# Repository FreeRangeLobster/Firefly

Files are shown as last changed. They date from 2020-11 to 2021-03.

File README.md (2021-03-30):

I am an aquarist enthusiast; I have a fully automated fish tank at home.
When my daughter Sofia was born two years ago, I couldn’t really dedicate as much spare time to my fish tank, and was spending it with her instead. She is very curious, and she found the fish tank buttons and indicators very attractive. She was always fiddling with them, pressing them, and enjoyed when the buttons would illuminate – to the point where I had to disable the button internal functionalities, as the poor fish would suffer from a stroboscopic effect otherwise. Cool in a party not cool in a tank
This is when I had an idea: what if I built an interactive table for Sofia, so she has her own buttons to play with (and leave the poor fish alone)? And that’s exactly what I did.
Over the past few weeks I spent some lunch times and evenings designing, building and programming a child friendly interactive table. This is what I did:

The first step was to find a controller with many IO, which should also be able to control addressable LEDs. After some research, I concluded that my weapon of choice will be an ESP-32.

The next task was to design the table and order all the components. My colleagues in the machine shop helped me manufacture the base plate. Note that I upcycled a small sand&water play table, so I only needed to design and manufacture the base to fit on top of it.

When the components arrived and the Perspex base was ready, I wired it all up. This only took a couple of days.

Then the programming started. Fortunately, there is a big community of open software/hardware and a lot of the libraries are already available, which helped me a lot.

On 20th December the system was ready for the tester (my daughter). She enjoyed it a lot and so far the table seems to be withstanding the abuse it’s getting.
I am not quite yet finished with the work. I would still like to add some sounds to it, and perhaps add IOT capabilities and connecting the table to Alexa – “Alexa, red lights please!”
So far we are all happy. Sofia has a custom-made interactive table, I learned something new, and the fish are finally enjoying some quiet time in their tank. This is only one small application aiming to encourage my daughter into STEM, it is never too early!

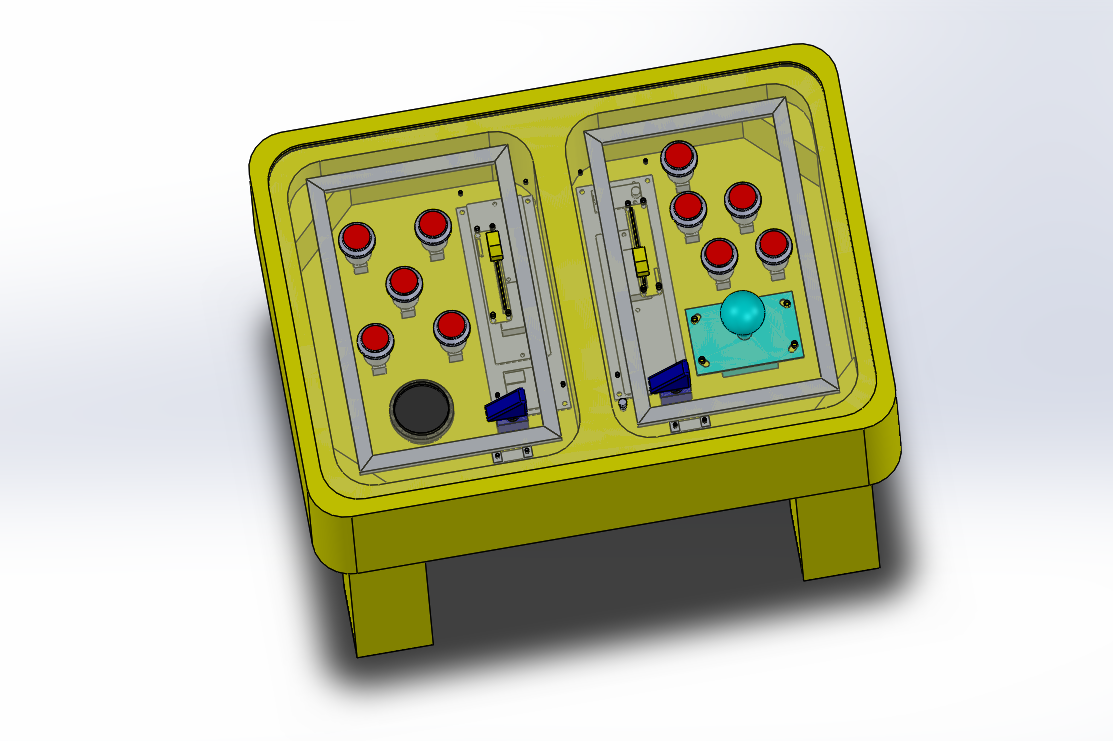
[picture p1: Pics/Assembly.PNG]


Application

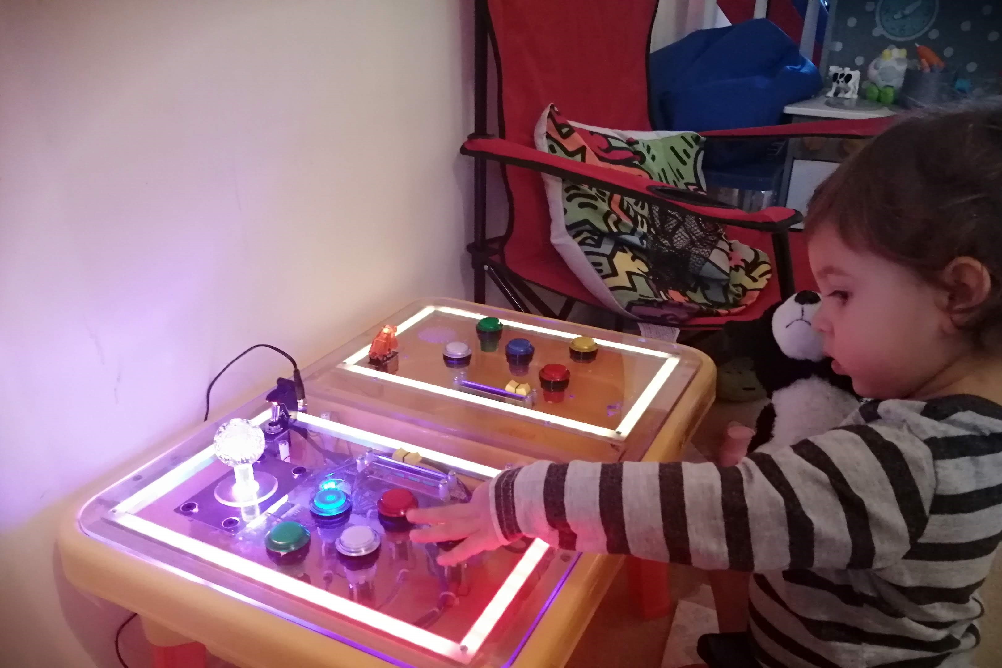
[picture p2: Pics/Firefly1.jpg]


Table with buttons and lights

#TheLight
Inputs
5 buttons
GPIO18
GPIO2
GPIO15
GPIO0

4 Joystick
GPIO36
GPIO39
GPIO34
GPIO35

5 Outputs
GPIO23
GPIO22
GPIO1
GPIO3
GPIO21

CAN
GPIO4 RX
GPIO5 TX

Connect 3V to power the buttons
Test the LEDs of the buttons

40*59*35

Priority Pins
gpio4
gpio5
gpio16
gpio17
gpio18
gpio19
gpio23
gpio25
gpio26
gpio27
gpio32
gpio33

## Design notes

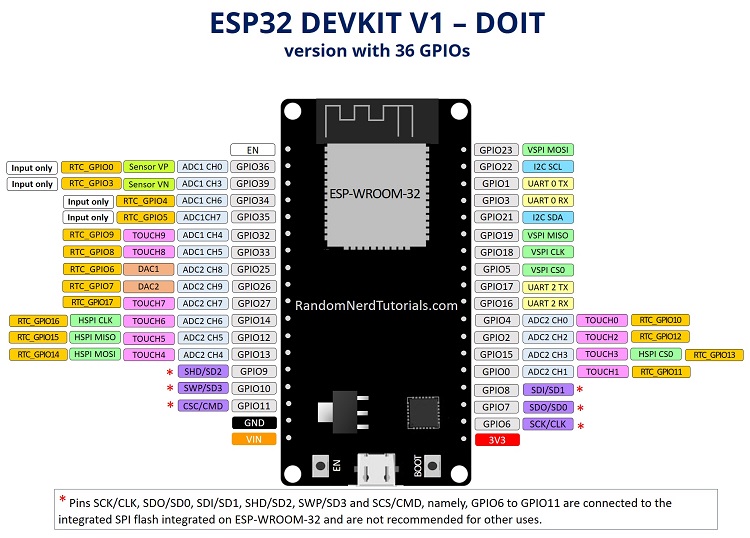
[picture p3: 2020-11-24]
Pics/ESP32-DOIT-DEVKIT-V1-Board-Pinout-36-GPIOs-updated.jpg

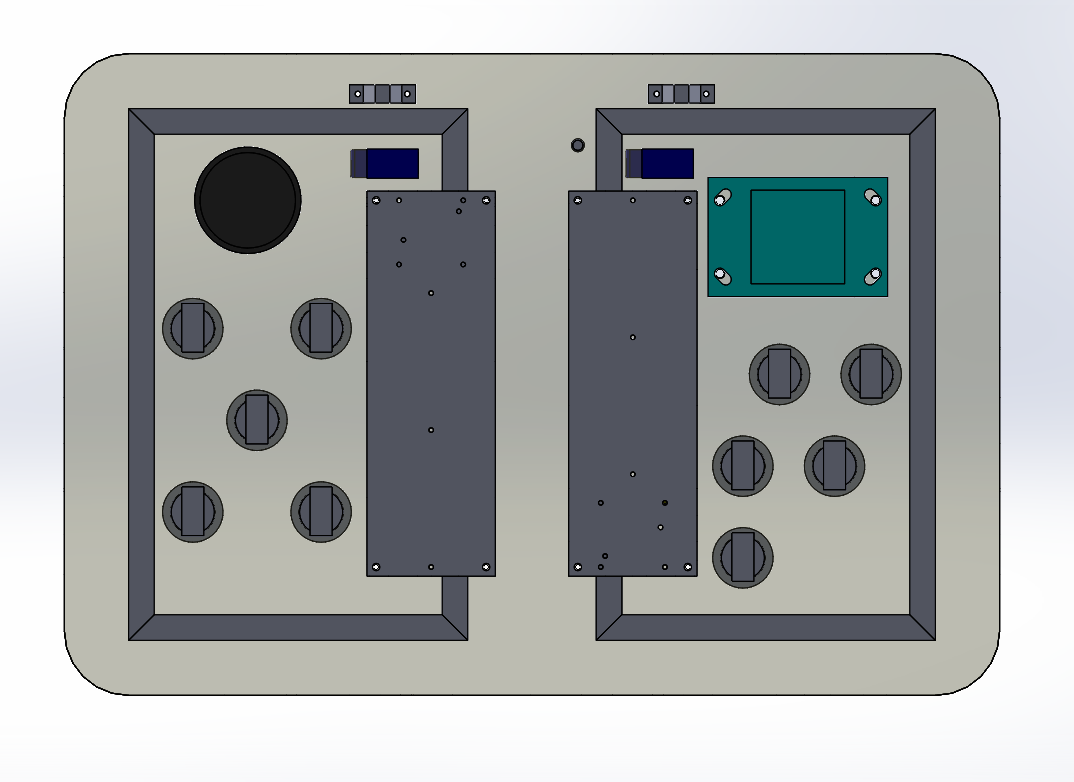
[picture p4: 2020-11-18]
Pics/BottomView.PNG

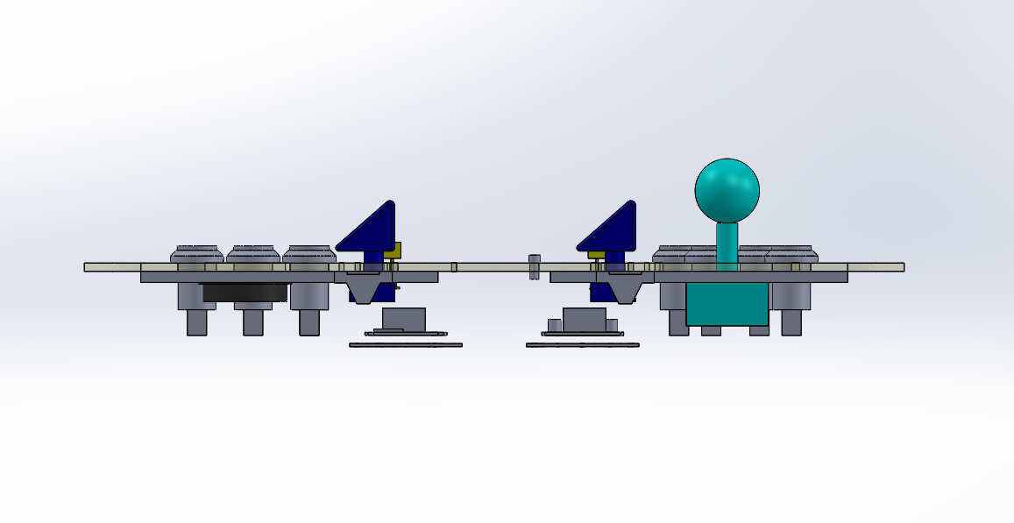
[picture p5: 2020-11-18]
Pics/Table-Less.PNG

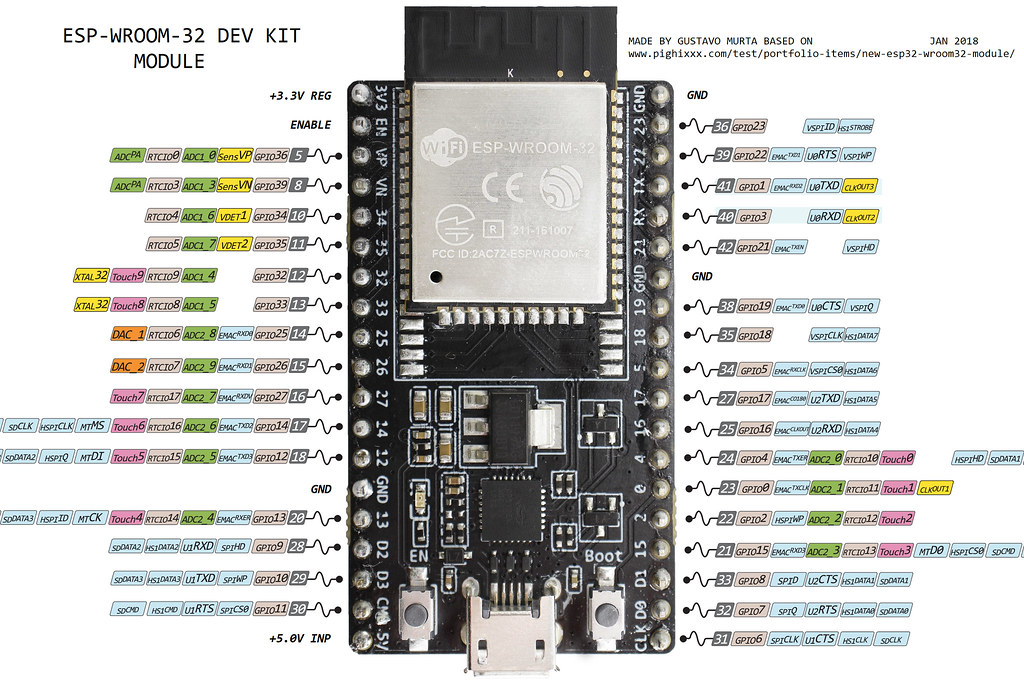
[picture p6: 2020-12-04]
Pics/40089095211_ec1fee0087_b.jpg

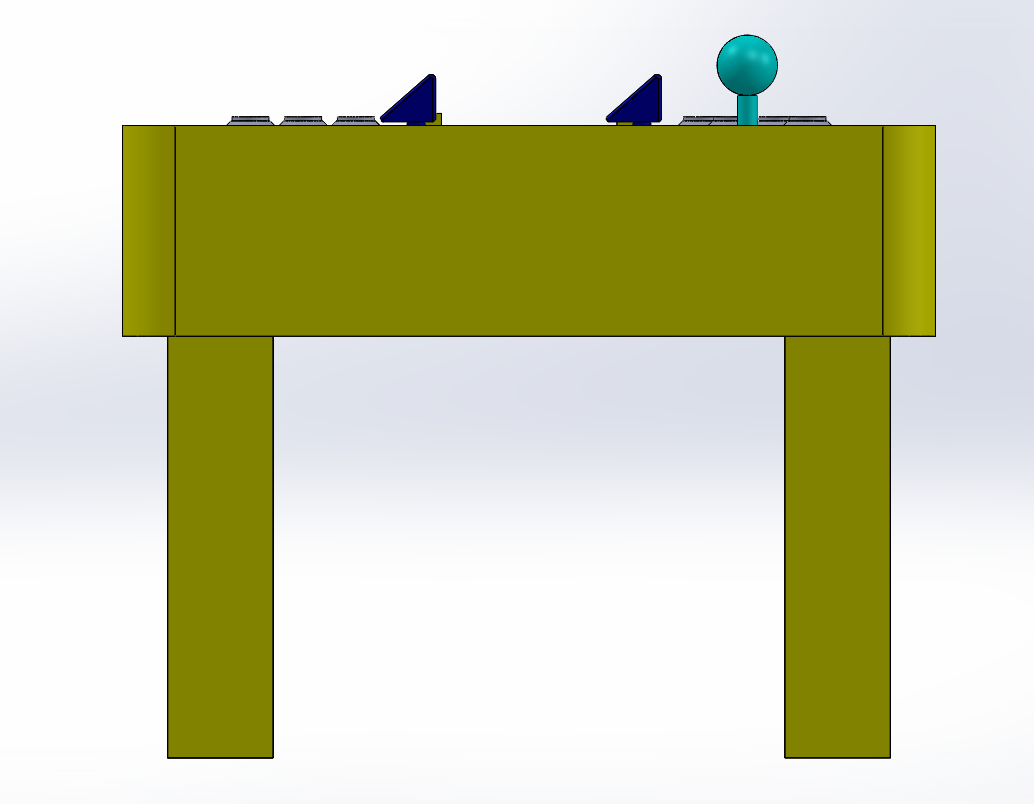
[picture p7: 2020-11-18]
Pics/Side.PNG

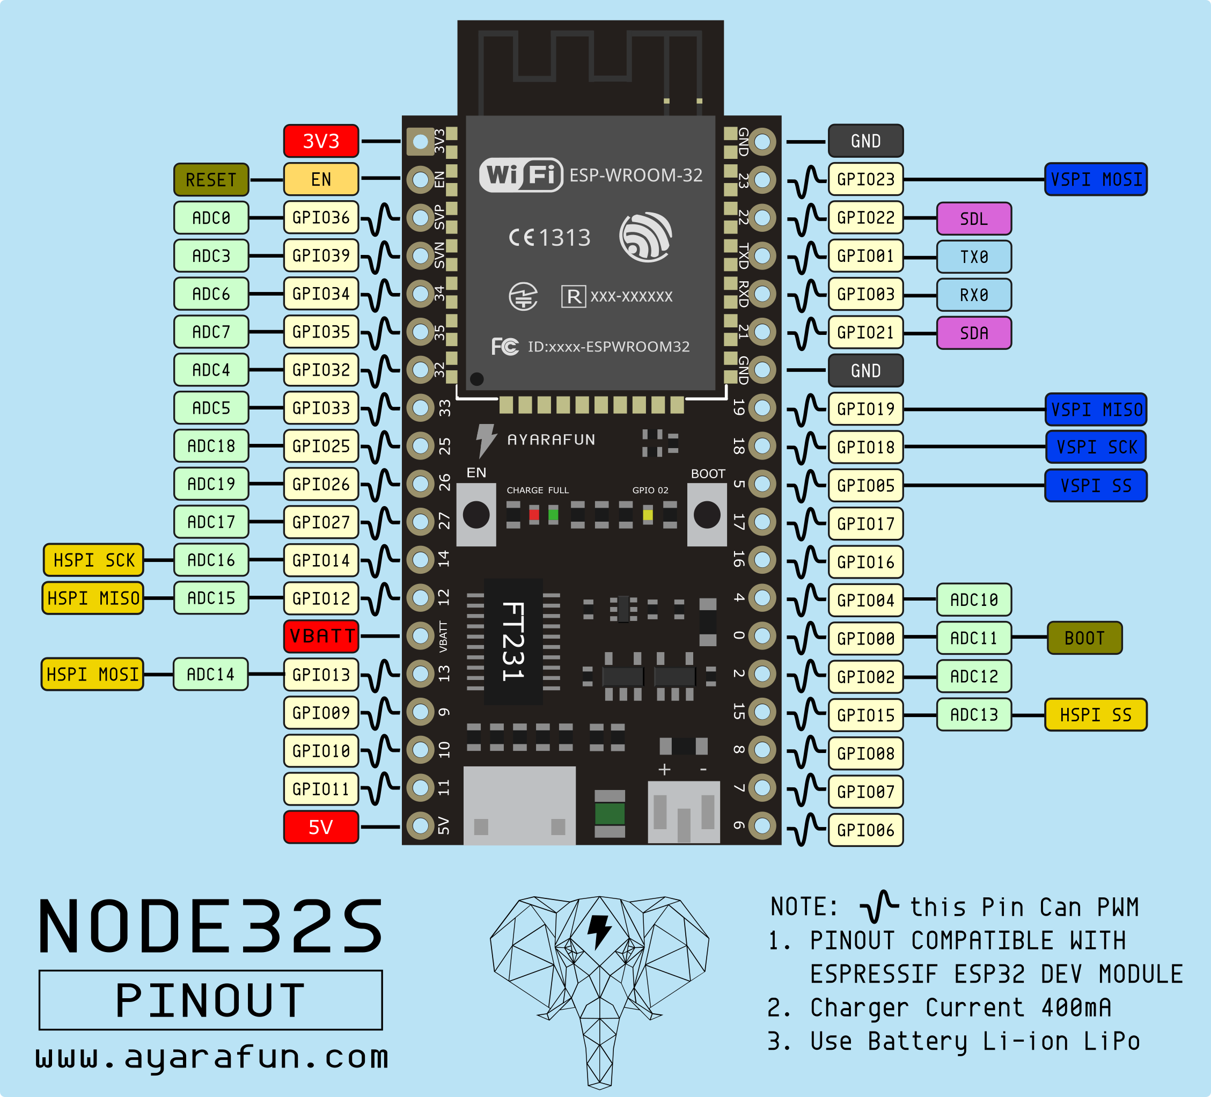
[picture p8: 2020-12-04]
Pics/Pins.png

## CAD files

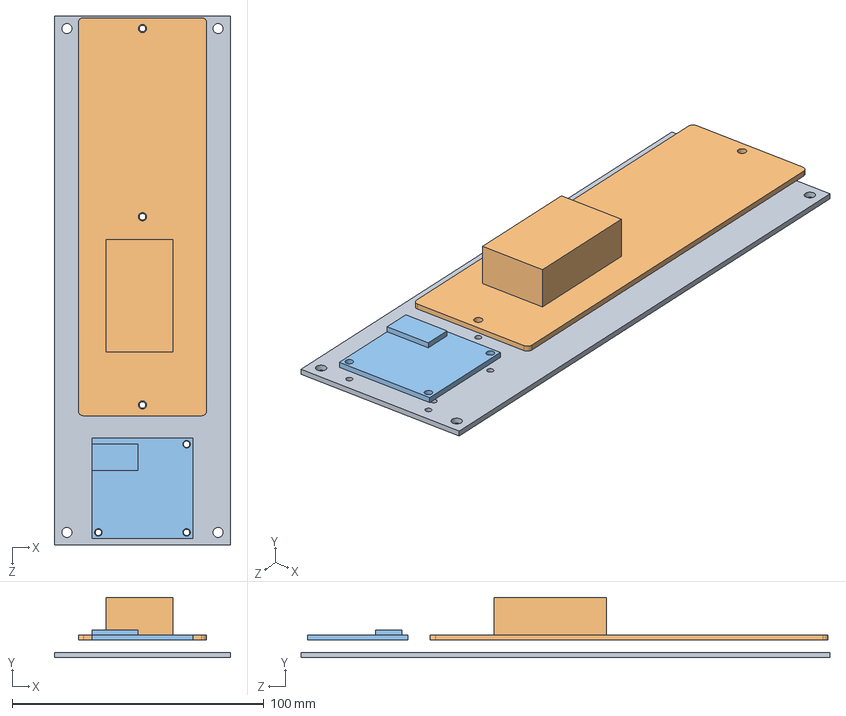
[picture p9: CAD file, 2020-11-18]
TheMechanics/AssPCB1.SLDASM
70.0 x 24.0 x 210.0 mm
PCBHolder
PCB
MP3

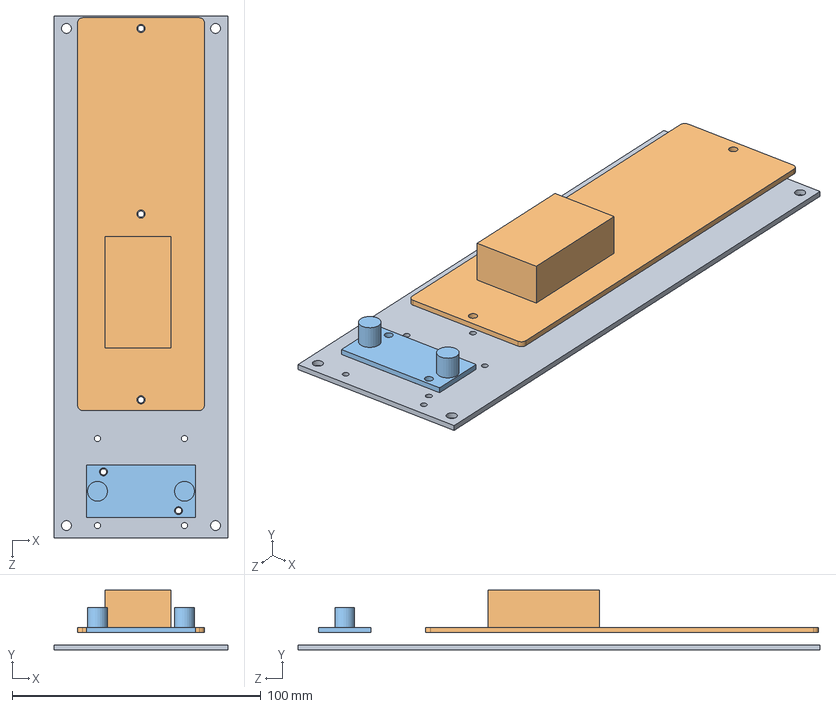
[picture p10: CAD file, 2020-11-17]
TheMechanics/AssPCB2.SLDASM
70.0 x 24.0 x 210.0 mm
PCBHolder
PCB
PSU

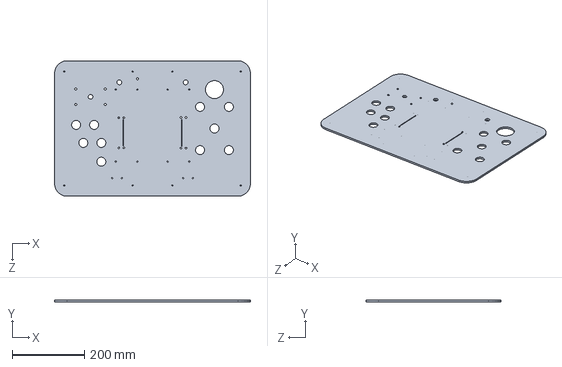
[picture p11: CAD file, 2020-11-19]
TheMechanics/Perspex Panel.SLDPRT
544.0 x 5.00 x 376.0 mm

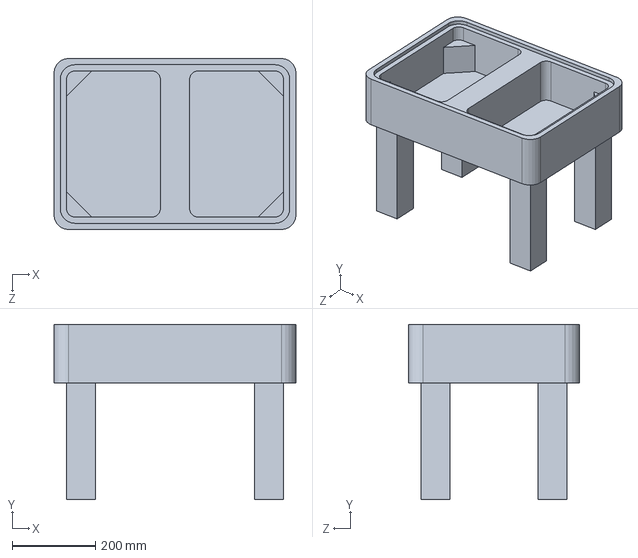
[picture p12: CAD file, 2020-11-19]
TheMechanics/Table.SLDPRT
580.0 x 420.0 x 410.0 mm

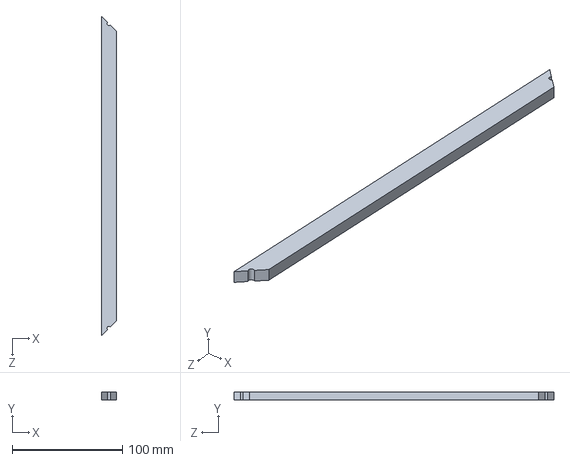
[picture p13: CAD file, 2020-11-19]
TheMechanics/ledChannelSide.SLDPRT
14.0 x 7.00 x 290.0 mm

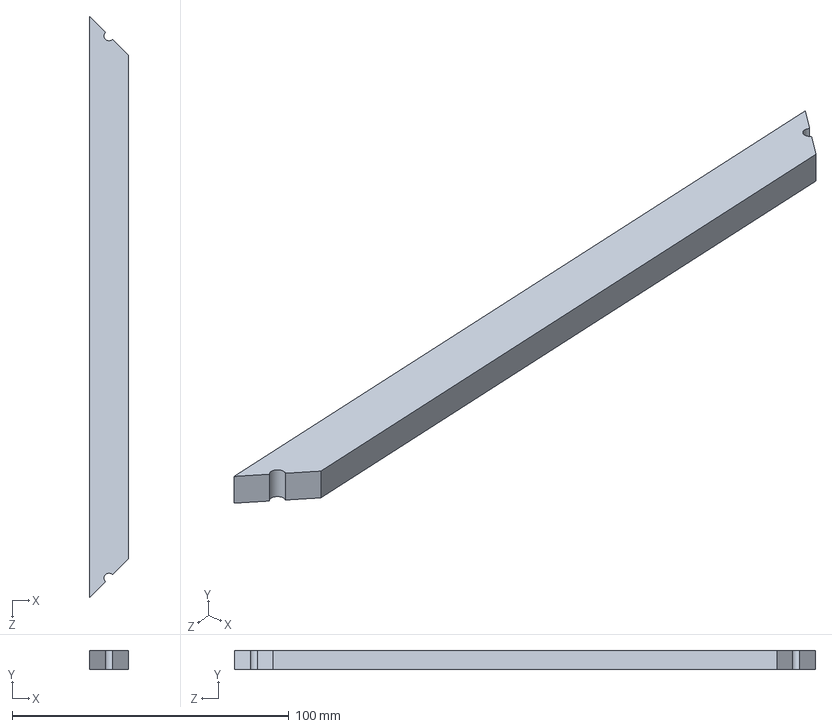
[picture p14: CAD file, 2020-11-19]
TheMechanics/ledChannelTop.SLDPRT
14.0 x 7.00 x 210.0 mm

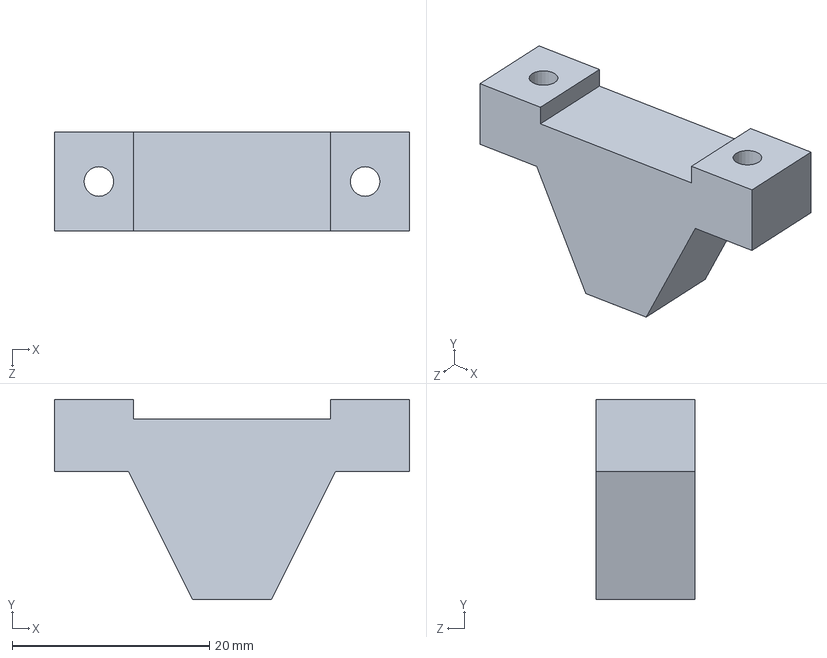
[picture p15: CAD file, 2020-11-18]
TheMechanics/USB Connector.SLDPRT
36.0 x 20.3 x 10.0 mm

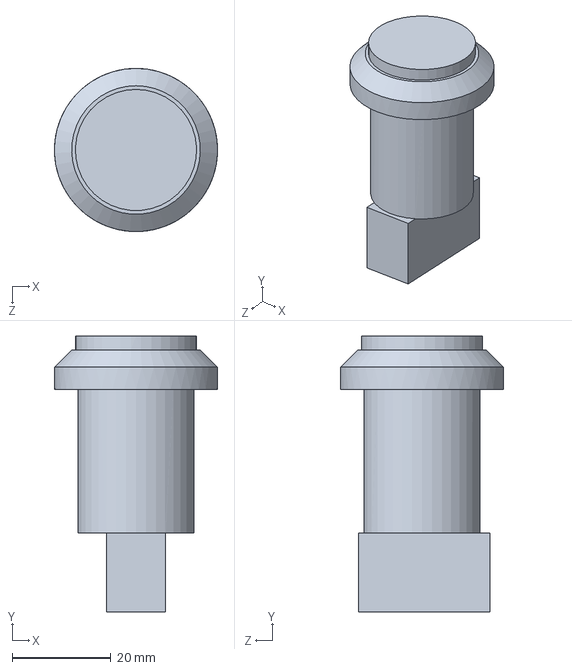
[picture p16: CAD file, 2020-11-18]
TheMechanics/prtPushButton.SLDPRT
33.0 x 55.8 x 33.0 mm

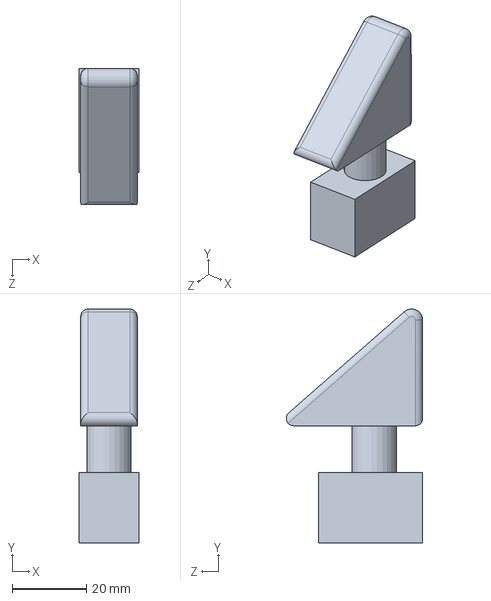
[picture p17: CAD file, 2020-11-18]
TheMechanics/MissileSwitch.SLDPRT
16.0 x 62.9 x 36.7 mm

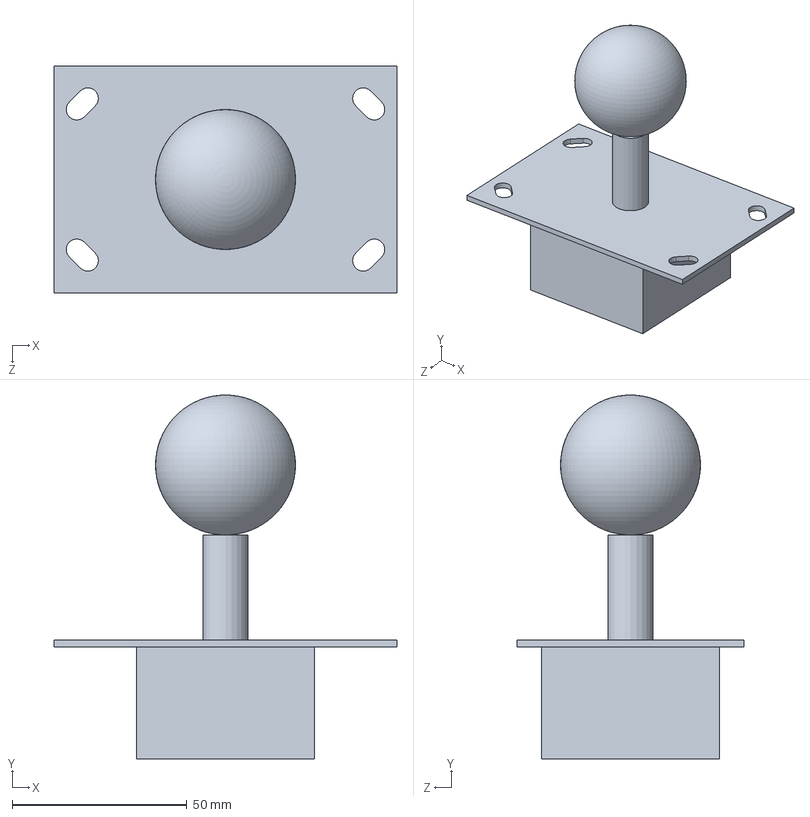
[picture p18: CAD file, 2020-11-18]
TheMechanics/Joystick.SLDPRT
98.0 x 104.0 x 65.0 mm

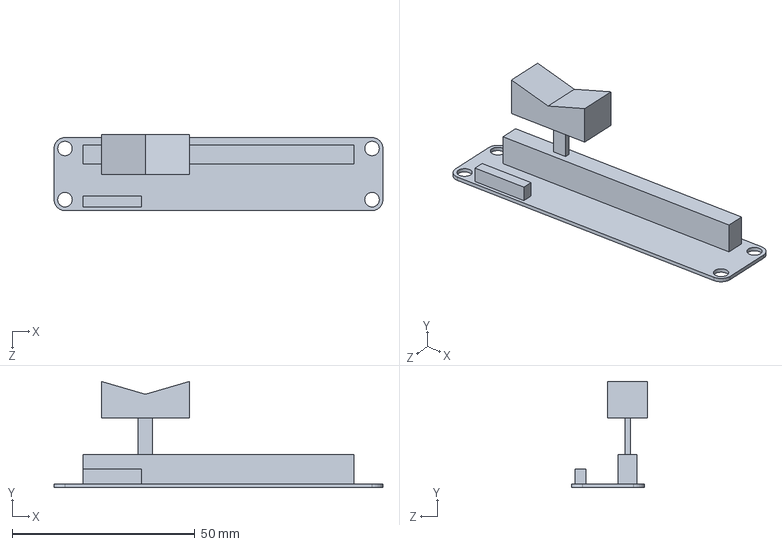
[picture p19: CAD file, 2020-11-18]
TheMechanics/Pot.SLDPRT
90.0 x 29.0 x 20.9 mm

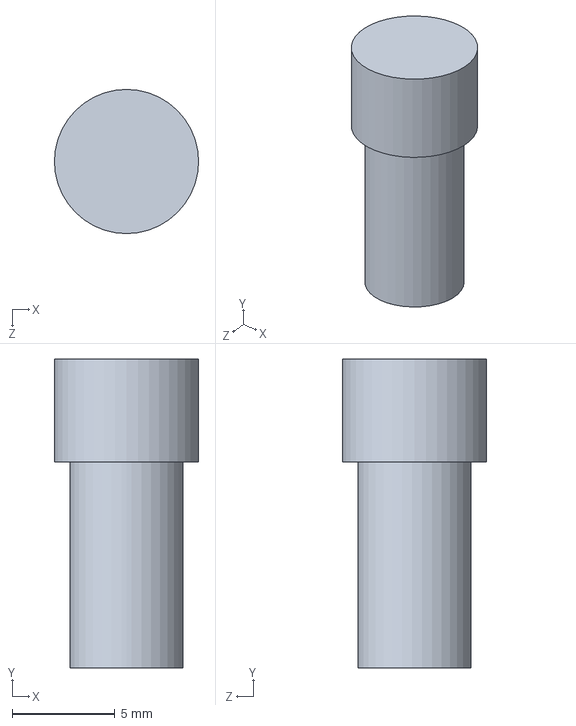
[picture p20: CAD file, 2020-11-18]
TheMechanics/PowerConnector.SLDPRT
7.00 x 15.0 x 7.00 mm

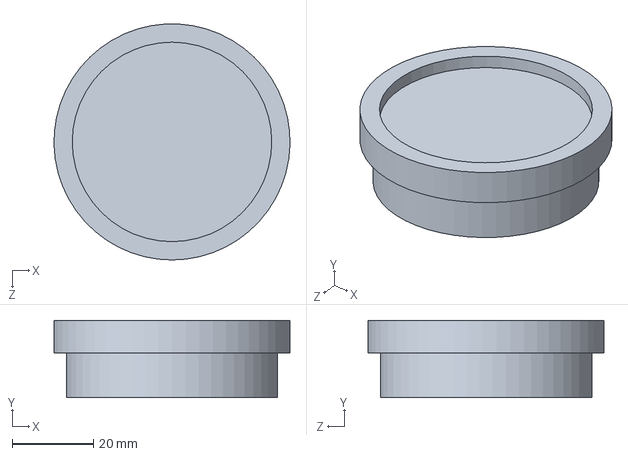
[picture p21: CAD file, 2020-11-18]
TheMechanics/Speaker.SLDPRT
58.0 x 19.0 x 57.9 mm

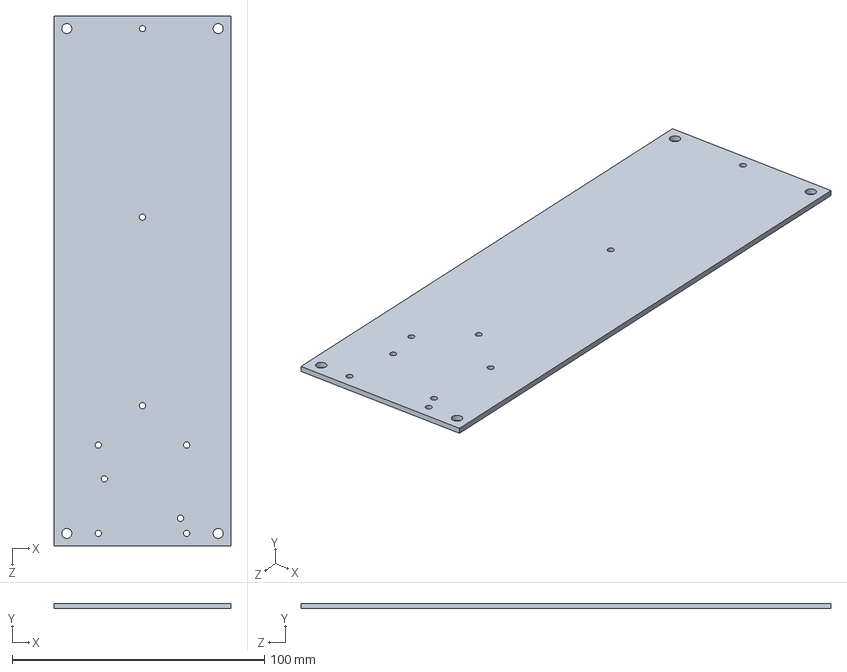
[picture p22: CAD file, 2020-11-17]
TheMechanics/PCBHolder.SLDPRT
70.0 x 2.00 x 210.0 mm

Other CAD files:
TheMechanics/PCB.SLDPRT
TheMechanics/PSU.SLDPRT
TheMechanics/Veroboard.SLDPRT
TheMechanics/MP3.SLDPRT
TheMechanics/PCBHolder.SLDDRW
TheMechanics/Perspex Panel.SLDDRW
TheMechanics/ledChannelSide.SLDDRW
TheMechanics/ledChannelTop.SLDDRW

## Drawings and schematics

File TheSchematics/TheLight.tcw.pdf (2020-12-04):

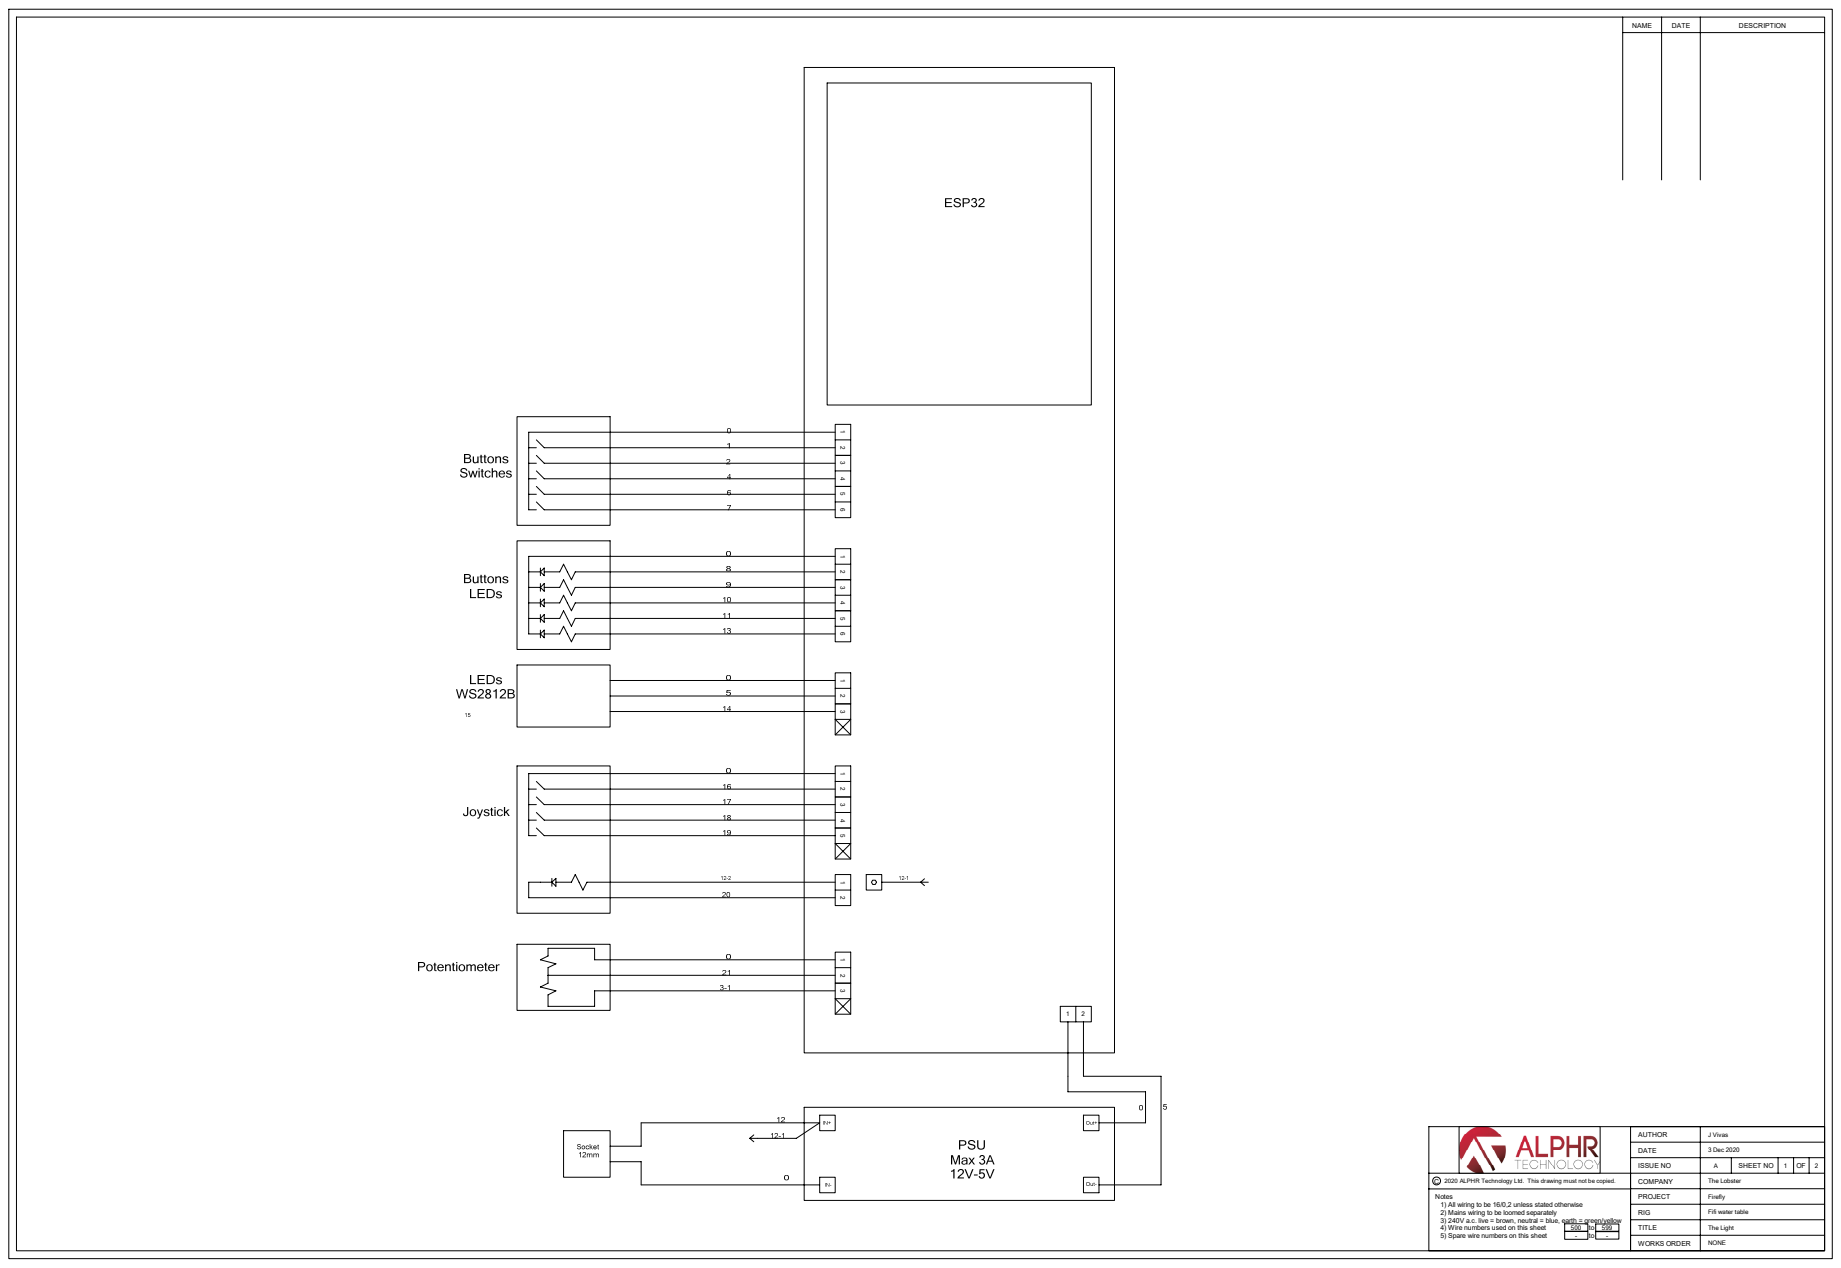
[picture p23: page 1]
NAME; DATE; DESCRIPTION

AUTHOR | J Vivas

DATE | 3 Dec 2020

ISSUE NO | A | SHEET NO | 1 | OF | 2

C 2020 ALPHR Technology Ltd. This drawing must not be copied. | COMPANY | The Lobster

Notes 1) All wiring to be 16/0,2 unless stated otherwise 2) Mains wiring to be loomed separately 3) 240V a.c. live = brown, neutral = blue, earth = green/yellow | PROJECT | Firefly

RIG | Fifi water table

4) Wire numbers used on this sheet
5) Spare wire numbers on this sheet

TITLE | The Light

WORKS ORDER | NONE

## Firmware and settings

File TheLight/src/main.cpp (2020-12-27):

#include <FastLED.h>

// How many leds in your strip?
#define NUM_LEDS 116

// For led chips like WS2812, which have a data line, ground, and power, you just
// need to define DATA_PIN.  For led chipsets that are SPI based (four wires - data, clock,
// ground, and power), like the LPD8806 define both DATA_PIN and CLOCK_PIN
// Clock pin only needed for SPI based chipsets when not using hardware SPI
#define DATA_PIN 3
#define CLOCK_PIN 13
#define LED 2
#define JoystickLamp 27



/*
*        S5                    S1
*|-------------------||-------------------|
*|                   ||                   |
*|                   ||                   |
*|S6               S8|| S4                | S2
*|                   ||                   |
*|       S7          ||        S3         |
*|-------------------||-------------------|
*/

//Right Side
//S8 + S2

//Left Side
//S6 + S4

#define S1s 0
#define S1e 11-1

#define S2s 11
#define S2e 11+18-1

#define S3s 11+18
#define S3e 11+18+11-1

#define S4s 11+18+11
#define S4e 11+18+11+18-1

#define S5s 11+18+11+18
#define S5e 11+18+11+18+11-1

#define S6s 11+18+11+18+11
#define S6e 11+18+11+18+11+18-1

#define S7s 11+18+11+18+11+18
#define S7e 11+18+11+18+11+18+11-1

#define S8s 11+18+11+18+11+18+11
#define S8e 11+18+11+18+11+18+11+18-1


// Potentiometer is connected to GPIO 34 (Analog ADC1_CH6) 
const int potPin = 34;

// Define the array of leds
CRGB leds[NUM_LEDS];
int ButtonSwitchesID [5]={19,23,35,36,39};
int ButtonLampsID [5]={4,5,16,17,18};
int JoystickID[4]={25,26,32,33};
static uint8_t hue = 0;
static uint8_t lastHue = 0;
int i;
int j;
int potValue;
int nBrightness=255;
boolean bDEBUG=0;

void setup() {    
  FastLED.addLeds<WS2812B, DATA_PIN, GRB>(leds, NUM_LEDS);  // GRB ordering is typical    

  //Stayalive Signal
  pinMode(LED,OUTPUT);
  //ledcAttachPin(LED, 0);

  pinMode(ButtonLampsID[0],OUTPUT);
  pinMode(ButtonLampsID[1],OUTPUT);
  pinMode(ButtonLampsID[2],OUTPUT);
  pinMode(ButtonLampsID[3],OUTPUT);
  pinMode(ButtonLampsID[4],OUTPUT);

   //Joystick lights
  pinMode(JoystickLamp,OUTPUT);

  //Buttons
  pinMode(ButtonSwitchesID[0],INPUT_PULLUP);
  pinMode(ButtonSwitchesID[1],INPUT_PULLUP);
  pinMode(ButtonSwitchesID[2],INPUT_PULLUP);
  pinMode(ButtonSwitchesID[3],INPUT_PULLUP);
  pinMode(ButtonSwitchesID[4],INPUT_PULLUP);

  //Joystick
  pinMode(JoystickID[0],INPUT_PULLUP);
  pinMode(JoystickID[1],INPUT_PULLUP);
  pinMode(JoystickID[2],INPUT_PULLUP);
  pinMode(JoystickID[3],INPUT_PULLUP);

  //Turn the LED on, then pause
  leds[0] = CRGB::Red;
  FastLED.show();
  delay(10);

  // Now turn the LED off, then pause
  leds[0] = CRGB::Black;
  FastLED.show();
  
  //Serial port for debugging
  Serial.begin(115200);
  Serial.println("Restarted");
  Serial.println("");

}

//void fadeall() { for(int i = 0; i < NUM_LEDS; i++) { leds[i].nscale8(250); } }
void fadeall() { for(int i = 0; i < NUM_LEDS; i++) { leds[i].nscale8(253); } }

void initialiseShow(){
  //Light up Joystick
    digitalWrite(JoystickLamp, HIGH); 
  //Light up buttons
  for(i=0;i<5;i++){
     digitalWrite(ButtonLampsID[i], HIGH);
     delay(100);
  }
  delay(100);
  for(i=0;i<5;i++){
     digitalWrite(ButtonLampsID[i], LOW); 
  }
  digitalWrite(JoystickLamp, LOW); 

  
  //Paint all and fade up
  hue=0;
  nBrightness=125;
  for(int k=0;k<NUM_LEDS;k++){
    leds[k] = CHSV(hue, 255, nBrightness);   
    delay(10);
    FastLED.show();
  }
 delay(200);
  //
  for(int l=0;l<255;l++){
    for(int k=0;k<NUM_LEDS;k++){
      leds[k] = CHSV(l, 255, nBrightness);  
    }
    delay(10);
    FastLED.show();
  }
   
 
}

void AllRed(int nBrightness){
  hue=5;
  lastHue=hue;
  for(int l=0;l<NUM_LEDS;l++){
    leds[l] = CHSV(hue, 255, nBrightness);
    
  }
   //FastLED.show(); 
}

void AllGreen(int nBrightness){
  hue=85;
  lastHue=hue;
  for(int k=0;k<NUM_LEDS;k++){
    leds[k] = CHSV(hue, 255, nBrightness);
    //leds[k] = CRGB::Green;
    
  }
   //FastLED.show(); 
}

void AllBlue(int nBrightness){
  hue=171;
  lastHue=hue;
  for(int k=0;k<NUM_LEDS;k++){
    leds[k] = CHSV(hue, 255, nBrightness);   
  }
   //FastLED.show(); 
}

void AllWhite(int nBrightness){
  hue=255;
  lastHue=hue;
  for(int k=0;k<NUM_LEDS;k++){
    leds[k] = CHSV(hue, 0, nBrightness);
  }
  // FastLED.show(); 
}

void AllYellow(int nBrightness){
  hue=55;
  lastHue=hue;
  for(int k=0;k<NUM_LEDS;k++){
    leds[k] = CHSV(hue, 255, nBrightness);
  }
   //FastLED.show(); 
}

void PaintTop(int nBrightness){
  //s3 and S7
  for(int k=0;k<NUM_LEDS;k++){
    //'Segment3
    if ((k>=S3s) && (k<=S3e)){
      leds[k] = CHSV(lastHue, 255, nBrightness);
    }
    else if((k>=S7s) && (k<=S7e)){
      //Segment7
      leds[k] = CHSV(lastHue, 255, nBrightness);
    }
    else{
      leds[k] = CHSV(lastHue, 0, 0);
    }
  }
}

void PaintDown(int nBrightness){
    for(int k=0;k<NUM_LEDS;k++){
      //'Segment3
      if ((k>=S1s) && (k<=S1e)){
        leds[k] = CHSV(lastHue, 255, nBrightness);
      }
      else if((k>=S5s) && (k<=S5e)){
        //Segment7
        leds[k] = CHSV(lastHue, 255, nBrightness);
      }
      else{
        leds[k] = CHSV(lastHue, 0, 0);
      }
  }
}

void PaintRightSide(int nBrightness){
    for(int k=0;k<NUM_LEDS;k++){
      //'Segment4
      if ((k>=S4s) && (k<=S4e)){
        leds[k] = CHSV(lastHue, 255, nBrightness);
      }
      else if((k>=S6s) && (k<=S6e)){
        //Segment6
        leds[k] = CHSV(lastHue, 255, nBrightness);
      }
      else{
        leds[k] = CHSV(lastHue, 0, 0);
      }
  }
}

void PaintLeftSide(int nBrightness){
    for(int k=0;k<NUM_LEDS;k++){
      //'Segment4
      if ((k>=S2s) && (k<=S2e)){
        leds[k] = CHSV(lastHue, 255, nBrightness);
      }
      else if((k>=S8s) && (k<=S8e)){
        //Segment6
        leds[k] = CHSV(lastHue, 255, nBrightness);
      }
      else{
        leds[k] = CHSV(lastHue, 0, 0);
      }
  }
}


enum eStates{ 
  eInitialise =0,
  eButtonGreen=1,
  eButtonRed =2,
  eButtonBlue=3,
  eButtonYellow=4,
  eButtonWhite=5,
  eJoystickUp=6,
  eJoystickDown=7,
  eJoystickLeft=8,
  eJoystickRight=9,
  eRandomLights=10,
  eRightLights=11,
  eLeftLights=12,
  eTop=13,
  eBottom=14,
  eLeft=15,
  eRight=16
};

enum eColor{  eGreen=0,
              eRed =1,
              eBlue =2,
              eYellow=3,
              eWhite=4};

int nState=eInitialise;

void ReadPotionemeter(){
  potValue = analogRead(potPin);
  nBrightness=potValue/16;
}

void loop() { 
  int a;
  delay(400);
  
  digitalWrite(JoystickLamp, HIGH);   

  initialiseShow();
       
  //Infinite loop
  do {  
   
  if ((digitalRead(LED)==LOW)){
    digitalWrite(LED, HIGH);
  }
  else{   
        digitalWrite(LED, LOW);
  }
    
  delay(50);
  Serial.println(potValue);

  //Buttons
  for(int i=0;i<5;i++){
    if(digitalRead(ButtonSwitchesID[i])==LOW) {
      //digitalWrite(ButtonLampsID[i], HIGH);
      Serial.print("Button ");
      Serial.println(i);
      nState=i+1;
    }
    else{
      //digitalWrite(ButtonLampsID[i], LOW);
    }
  }

  //Joystick
  for(int i=0;i<4;i++){
    if(digitalRead(JoystickID[i])==LOW) {
      //digitalWrite(ButtonLampsID[i], HIGH);
      Serial.print("Joy ");
      Serial.println(i);
      nState=i+1+5;
    }
    else{
      //digitalWrite(ButtonLampsID[i], LOW);
    }
  }

  Serial.print("State: ");
  Serial.println(nState);

  switch (nState){
    case eInitialise:
     digitalWrite(ButtonLampsID[0], LOW);
     digitalWrite(ButtonLampsID[1], LOW);
     digitalWrite(ButtonLampsID[2], LOW);
     digitalWrite(ButtonLampsID[3], LOW);
     digitalWrite(ButtonLampsID[4], LOW);
     j=0;
     hue=0;
     nState=eRightLights;
    break;

    case eButtonGreen:
      //Turn button red
      Serial.println("Green Button");
      digitalWrite(ButtonLampsID[0], HIGH);
      AllGreen(nBrightness);
      nState=eInitialise;  
    break;

    case eButtonRed:
      //Turn button red
      Serial.println("Red Button");
      digitalWrite(ButtonLampsID[1], HIGH);
      AllRed(nBrightness);
      //Turn the leds RED
      nState=eInitialise;
    break;

    case eButtonBlue:
      //Turn button red
      Serial.println("Blue Button");
      digitalWrite(ButtonLampsID[2], HIGH);
      AllBlue(nBrightness);
      nState=eInitialise;
    break;

    case eButtonYellow:
      Serial.println("Yellow Button");
      digitalWrite(ButtonLampsID[3], HIGH);
      AllYellow(nBrightness);
      nState=eInitialise;
    break;

    case eButtonWhite:
      //Turn button red
      Serial.println("White Button");
      digitalWrite(ButtonLampsID[4], HIGH);
      AllWhite(nBrightness);
      nState=eInitialise;
    break;

    case eJoystickUp:
      Serial.println("eJoystickUp");
      PaintTop(nBrightness);
        //FastLED.show();
      nState=eInitialise;
    break;

    case eJoystickDown:
      PaintDown(nBrightness);
      nState=eInitialise;
    break;

    case eJoystickLeft:
      PaintLeftSide(nBrightness);
      nState=eInitialise;
    break;

    case eJoystickRight:
      PaintRightSide(nBrightness);
      nState=eInitialise;
    break;

    case eRightLights:
      j = j+1;      
      if (j< NUM_LEDS){
          //for(int i = 0; i < NUM_LEDS; i++) {
          // Set the i'th led to red 
          leds[j] = CHSV(hue++, 255, nBrightness);
          // Show the leds
          FastLED.show(); 
          // now that we've shown the leds, reset the i'th led to black
          // leds[i] = CRGB::Black;
          fadeall();
          // Wait a little bit before we loop around and do it again
          //delay(5);
          ReadPotionemeter();

        
          //turn off the lights
          for(int i=0;i<5;i++){
            digitalWrite(ButtonLampsID[i], LOW); 
          }
          a=j % 5;
          digitalWrite(ButtonLampsID[a], HIGH); 


      }
      else{
        j=NUM_LEDS;
        nState=eLeftLights;
        //Turn Off buttons
        for(int i=0;i<5;i++){
            digitalWrite(ButtonLampsID[i], LOW); 
        }
        //Turn On Joystic
         digitalWrite(JoystickLamp, HIGH); 

      }
      break;

        
    case eLeftLights:
      j=j-1;
      if (j>=0){
                 // for(int i = (NUM_LEDS)-1; i >= 0; i--) {
        // Set the i'th led to red 
        leds[j] = CHSV(hue++, 255, nBrightness);
        // Show the leds
        FastLED.show();
        // now that we've shown the leds, reset the i'th led to black
        // leds[i] = CRGB::Black;
        fadeall();
        // Wait a little bit before we loop around and do it again
        //delay(5);
        ReadPotionemeter();
      }
      else{
        j=0;
        nState=eRightLights;
        //Turn On Joystic
         digitalWrite(JoystickLamp, LOW); 
      }
    break;

    case eTop:
      
    break;

    case eBottom:
    break;

    case eRight:
    break;

     case eLeft:
    break;
    
    default:
    break;
    }

    FastLED.show();

  } while (true);
}

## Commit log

2020-11-14 LAying out the components' positions on the table
    [AssTable.SLDASM, Joystick.SLDPRT, MissileSwitch.SLDPRT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]
2020-11-18 Getting Mechanical Drawings Ready
    [AssPCB1.SLDASM, AssTable.SLDASM, Joystick.SLDPRT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]
2020-11-19 Drawings ready for machining perspex
    [AssTable.SLDASM, Perspex Panel.SLDDRW, Perspex Panel.SLDPRT]
2020-11-19 Saving drawing in PDF in pics
    [Perspex Panel.SLDDRW]
2020-11-22 Getting LED Channel drawings ready
    [ledChannelSide.SLDDRW, ledChannelTop.SLDDRW]
2020-11-23 Mechanical Drawings Ready for LED Ali Channels
    [ledChannelSide.SLDDRW, ledChannelTop.SLDDRW]
2020-11-23 Neopixel prototype working
2020-11-23 Drawing PCB holder
    [PCBHolder.SLDDRW]
2020-12-04 Adding schematics for buttons connection and tidng up program
2020-12-09 Adding info to the schematic
2020-12-17 The light wiring finished- time to code!
2020-12-23 Setting functionality to buttons and adding states to the light display
